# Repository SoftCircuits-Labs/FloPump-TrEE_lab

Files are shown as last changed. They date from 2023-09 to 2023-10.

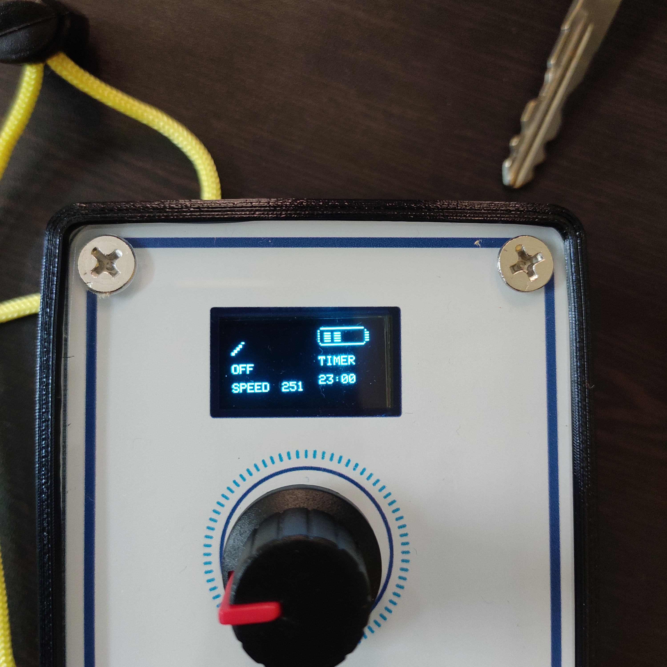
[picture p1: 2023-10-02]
AFC-DOCS/Images/Flopump_display.jpg

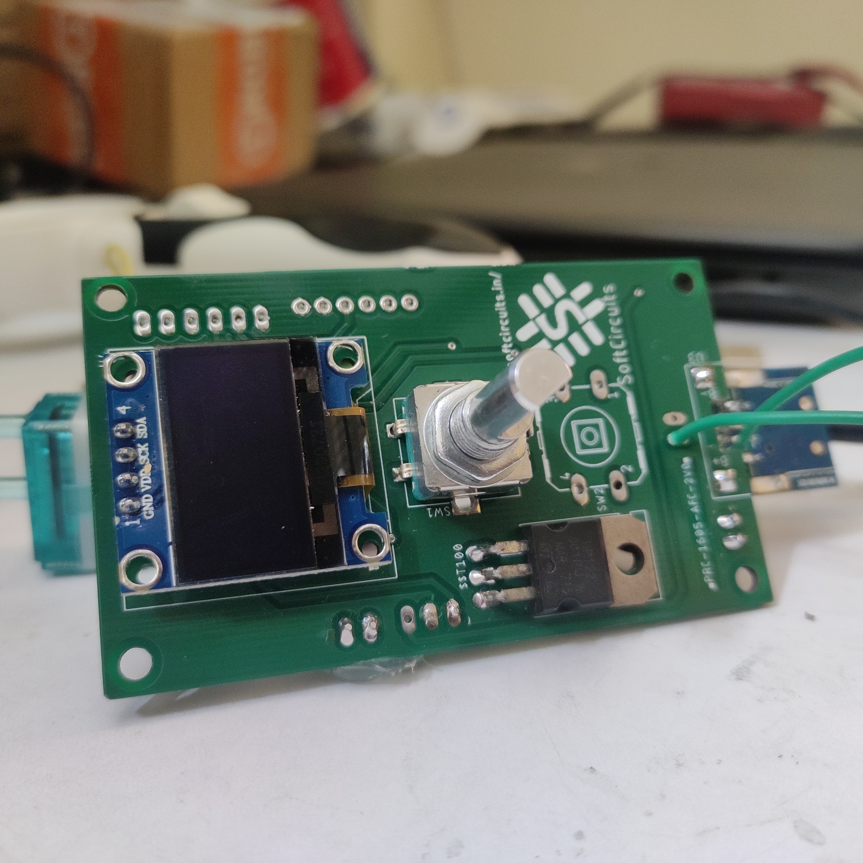
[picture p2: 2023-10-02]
AFC-DOCS/Images/Flopump_PCB.jpg

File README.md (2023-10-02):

<h1 align="center">AirFlo-pump</h1>

## About the  AirFlo-Pump Device
It is an air sampler device built for use in the applications that require a regulated air flow, for example sampling of VOCs from plants, room etc., or to generate a regulaed air flow in wind-tunnel experiments.

## Contents
<!---List file contents of the project, in table.--->

| File/folder | Description |
|---|---|
| `AFC-CODE` | Firmware for the device |
| `AFC-DOCS` | Device Images, User's Guide and other documents related to the device|
| `AFC-ENCLOSURE` | 3D Design files and DXF files for the enclosure |
| `AFC-PCB` | PCB Schematic files, board files and Gerber files |
| `LICENSE` | The license for the project. |
| `README.md` | This README file. |

## Built With
* [][Arduino-url]
* [][Eagle-url]
* [][Inventor-url]

## Usage

## Contact 

<!-- MARKDOWN LINKS & IMAGES -->
<!-- https://www.markdownguide.org/basic-syntax/#reference-style-links -->

[Arduino-l]: https://img.shields.io/badge/arduino-00878F?style=for-the-badge&logo=arduino&logoColor=white
[Arduino-url]: https://www.arduino.cc/
[Eagle-l]: https://img.shields.io/badge/Autodesk_Eagle-000000?style=for-the-badge&logo=autodesk&logoColor=white
[Eagle-url]: https://www.autodesk.in/products/eagle/overview
[Inventor-l]: https://img.shields.io/badge/Autodesk_Inventor-000000?style=for-the-badge&logo=autodesk&logoColor=white
[Inventor-url]: https://www.autodesk.in/products/inventor/overview

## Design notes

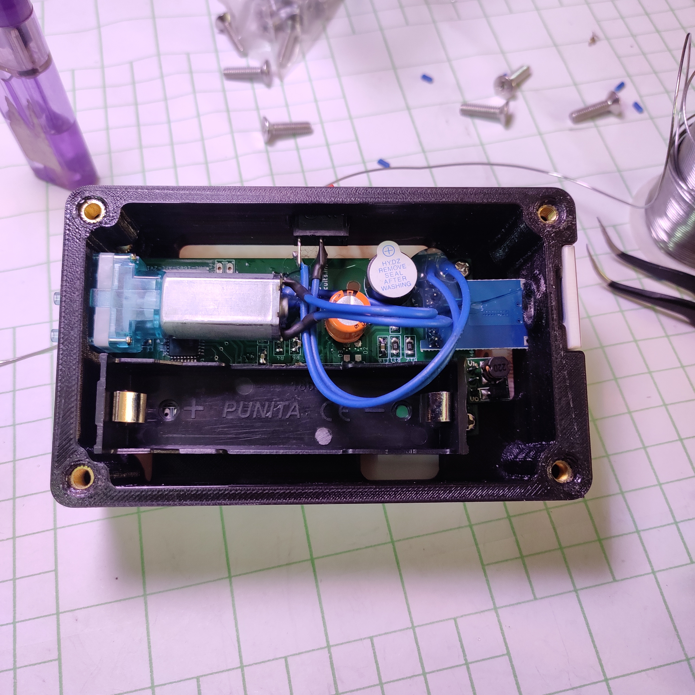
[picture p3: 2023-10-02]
AFC-DOCS/Images/Flopump_back-in.jpg

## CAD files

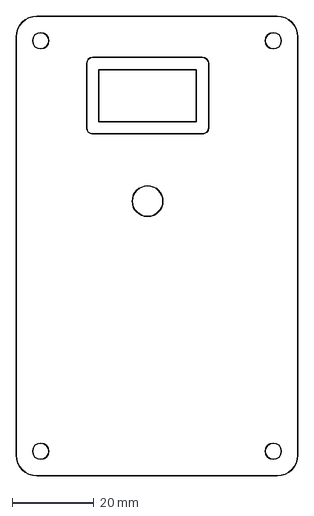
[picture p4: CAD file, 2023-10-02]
AFC-ENCLOSURE/dxf/front_acrylic.dxf
69.1 x 112.7 mm

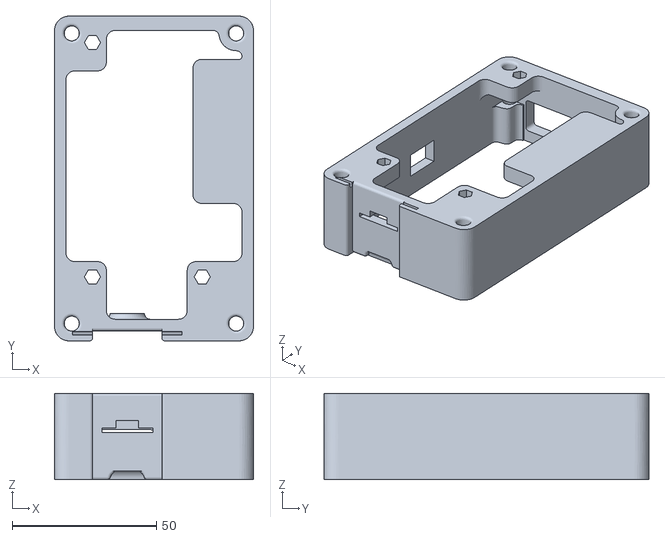
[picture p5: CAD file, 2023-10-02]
AFC-ENCLOSURE/STL/side_frame_v_2.stl
69.0 x 112.7 x 30.0

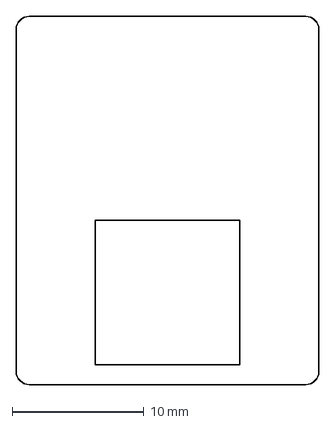
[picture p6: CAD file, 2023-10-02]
AFC-ENCLOSURE/dxf/usb_cap.dxf
23.0 x 28.0 mm

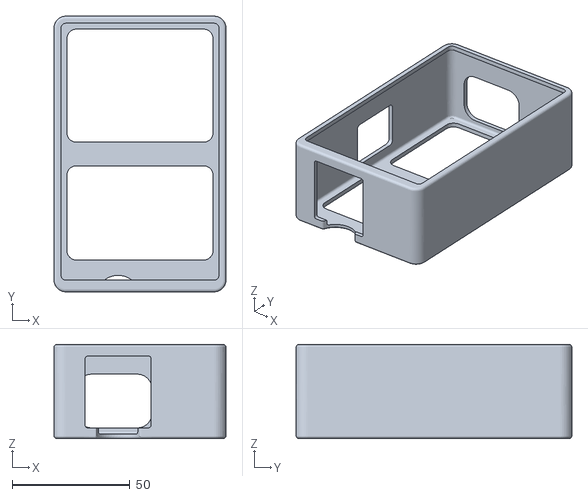
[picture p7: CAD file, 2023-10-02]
AFC-ENCLOSURE/STL/rubber_cover_v2.stl
73.0 x 117.0 x 40.0

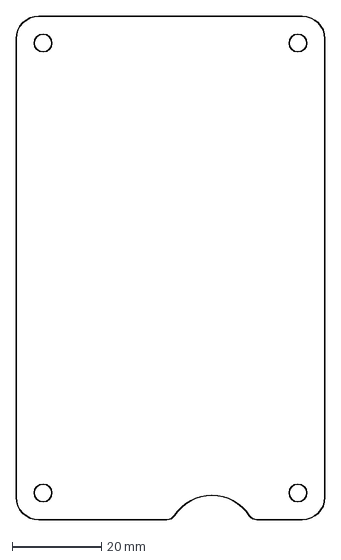
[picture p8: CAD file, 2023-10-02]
AFC-ENCLOSURE/dxf/back_acrylic.dxf
69.1 x 112.7 mm

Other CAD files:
AFC-ENCLOSURE/STL/side_frame.stl
AFC-ENCLOSURE/STL/rubber_cover.stl

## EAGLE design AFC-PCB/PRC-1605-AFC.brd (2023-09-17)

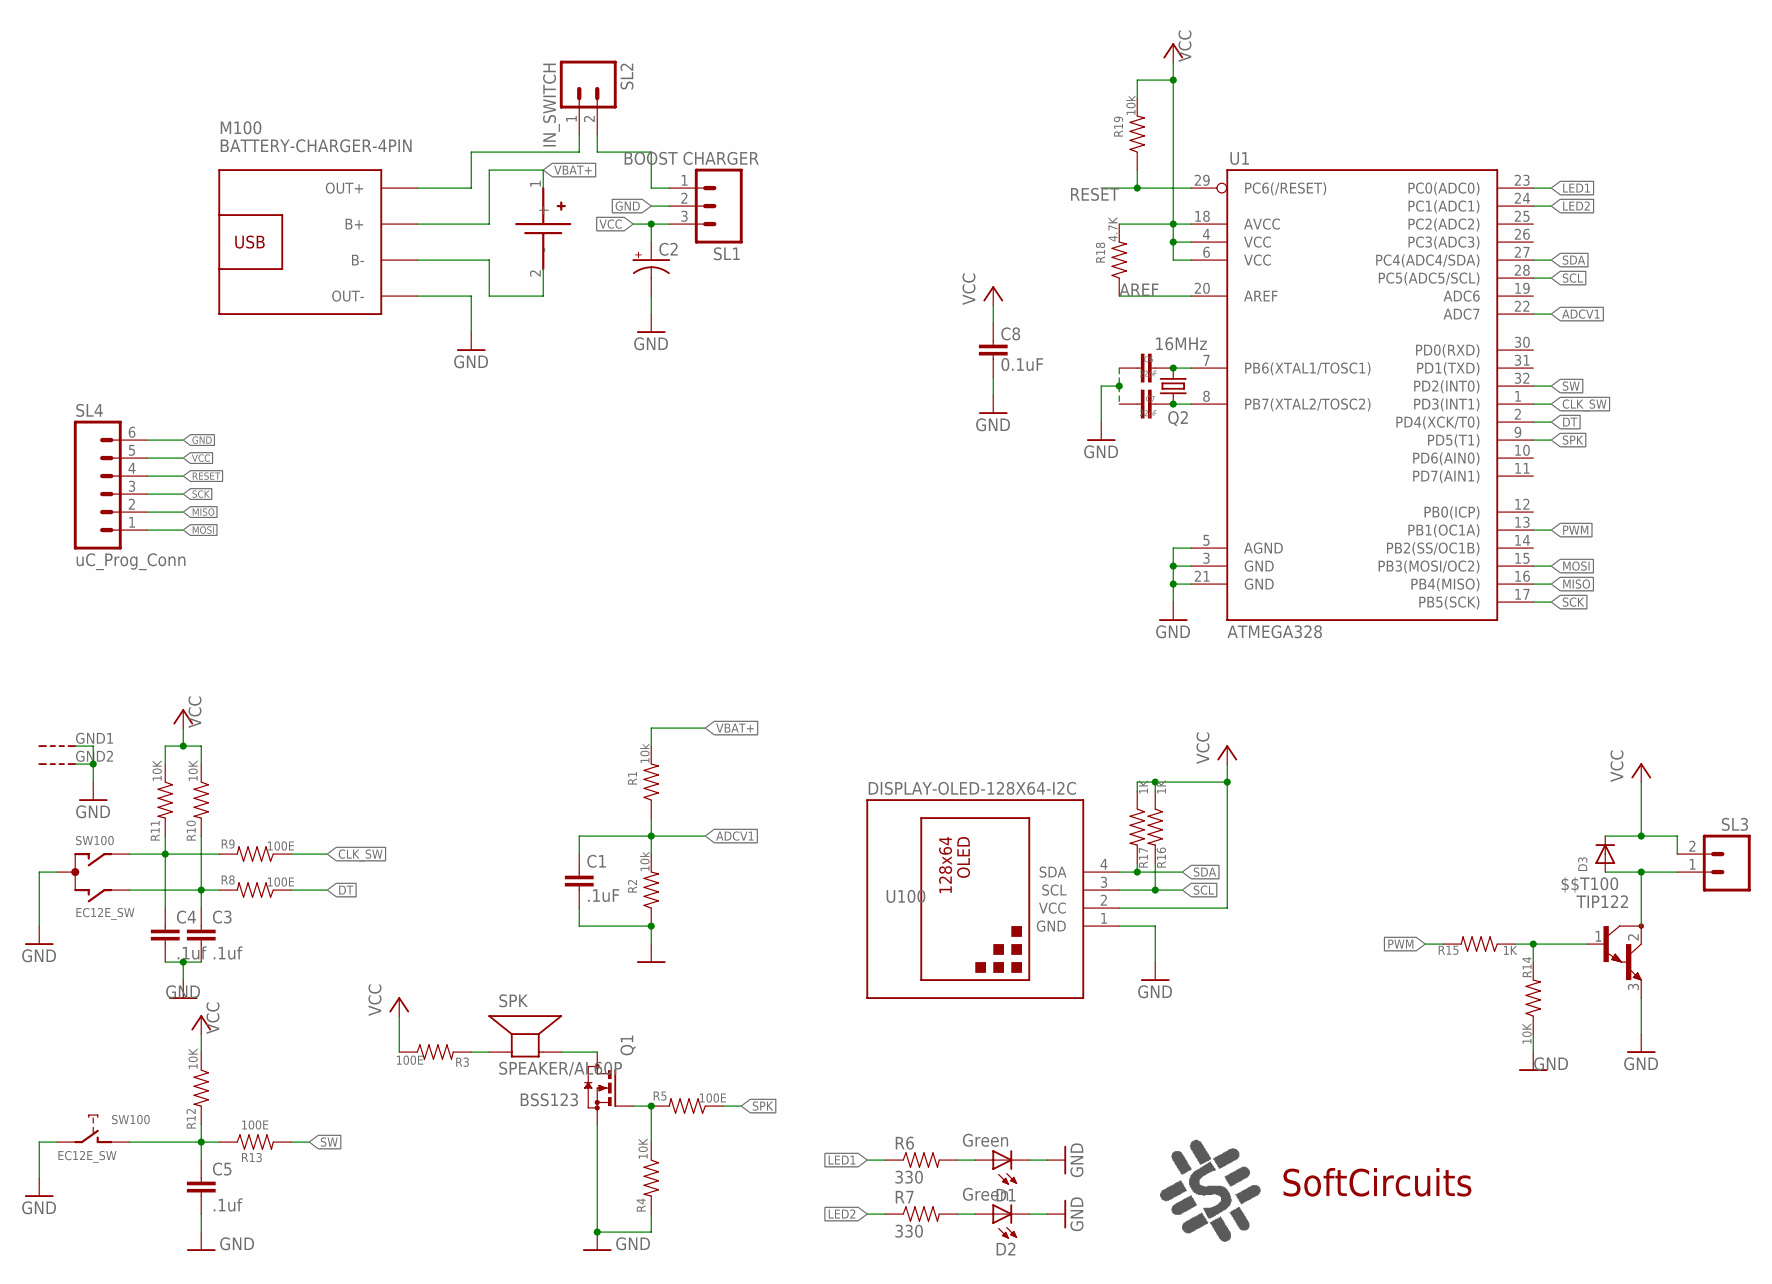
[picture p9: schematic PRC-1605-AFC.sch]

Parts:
$$T100: TIP122; TO220
C1: .1uF; C1206
C2: CPOL-USE2.5-7; E2,5-7
C3, C4, C5: .1uf; C1206
C6, C7: 22pF; C1206
C8: 0.1uF; C1206
D1, D2: Green; CHIPLED_1206
D3: DIODESMA; SMADIODE
LOGO100: SC_LOGO
M100: BATTERY-CHARGER-4PIN; BATTERY-CHARGER-LI-4PIN
Q1: BSS123; SOT23
Q2: 16MHz; HC49UP
R1, R2, R19: 10k; 1206
R3, R5, R8, R9, R13: 100E; 1206
R4, R10, R11, R12, R14: 10K; 1206
R6, R7: 330; 1206
R15, R16, R17: 1K; 1206
R18: 4.7K; 1206
SL1: BOOST CHARGER; 03P
SL2: IN_SWITCH; 02P
SL3: M02; 02P
SL4: uC_Prog_Conn; 06P
SPK: SPEAKER/AL60P; AL60P
SW100: EC12E_SW; ALPS_EC12E_SW
U1: ATMEGA328; TQFP32-08
U100: DISPLAY-OLED-128X64-I2C
U$2: BLOSSOM-BLM-18650-1PCS

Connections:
ADCV1: C1.1, R1.1, R2.2, U1.22 (ADC7)
AREF: R18.1, U1.20 (AREF)
CLK_SW: R9.1, U1.1 (PD3(INT1))
DT: R8.1, U1.2 (PD4(XCK/T0))
GND: $$T100.3 (E), C1.2, C2.-, C3.2, C4.2, C5.2, C6.2, C7.2, C8.1, D1.C, D2.C, M100.OUT-, Q1.2 (S), R2.1, R4.2, R14.1, SL1.2, SL4.6, SW100.C, SW100.E (2), SW100.GND1 (G), SW100.GND2 (G), U1.3 (GND), U1.5 (AGND), U1.21 (GND), U100.1 (GND)
LED1: R6.1, U1.23 (PC0(ADC0))
LED2: R7.1, U1.24 (PC1(ADC1))
MISO: SL4.2, U1.16 (PB4(MISO))
MOSI: SL4.1, U1.15 (PB3(MOSI/OC2))
unnamed: R3.2, SPK.1 (+)
unnamed: C5.1, R12.2, R13.1, SW100.D (1)
unnamed: Q1.3 (D), SPK.2 (-)
unnamed: SL1.1, SL2.2
unnamed: C4.1, R9.2, R11.2, SW100.A
unnamed: M100.B-, U$2.2 (-)
unnamed: Q1.1 (G), R4.1, R5.2
unnamed: D2.A, R7.2
unnamed: C3.1, R8.2, R10.2, SW100.B
unnamed: C7.1, Q2.1, U1.8 (PB7(XTAL2/TOSC2))
unnamed: C6.1, Q2.2, U1.7 (PB6(XTAL1/TOSC1))
unnamed: D1.A, R6.2
unnamed: $$T100.1 (B), R14.2, R15.1
unnamed: $$T100.2 (C), D3.A, SL3.1
PWM: R15.2, U1.13 (PB1(OC1A))
RESET: R19.1, SL4.4, U1.29 (PC6(/RESET))
SCK: SL4.3, U1.17 (PB5(SCK))
SCL: R16.2, U1.28 (PC5(ADC5/SCL)), U100.3 (SCL)
SDA: R17.2, U1.27 (PC4(ADC4/SDA)), U100.4 (SDA)
SPK: R5.1, U1.9 (PD5(T1))
SW: R13.2, U1.32 (PD2(INT0))
VBAT+: M100.B+, R1.2, U$2.1 (+)
VCC: C2.+, C8.2, D3.C, R3.1, R10.1, R11.1, R12.1, R16.1, R17.1, R18.2, R19.2, SL1.3, SL3.2, SL4.5, U1.4 (VCC), U1.6 (VCC), U1.18 (AVCC), U100.2 (VCC)
VOUT_CHG: M100.OUT+, SL2.1

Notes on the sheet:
SoftCircuits

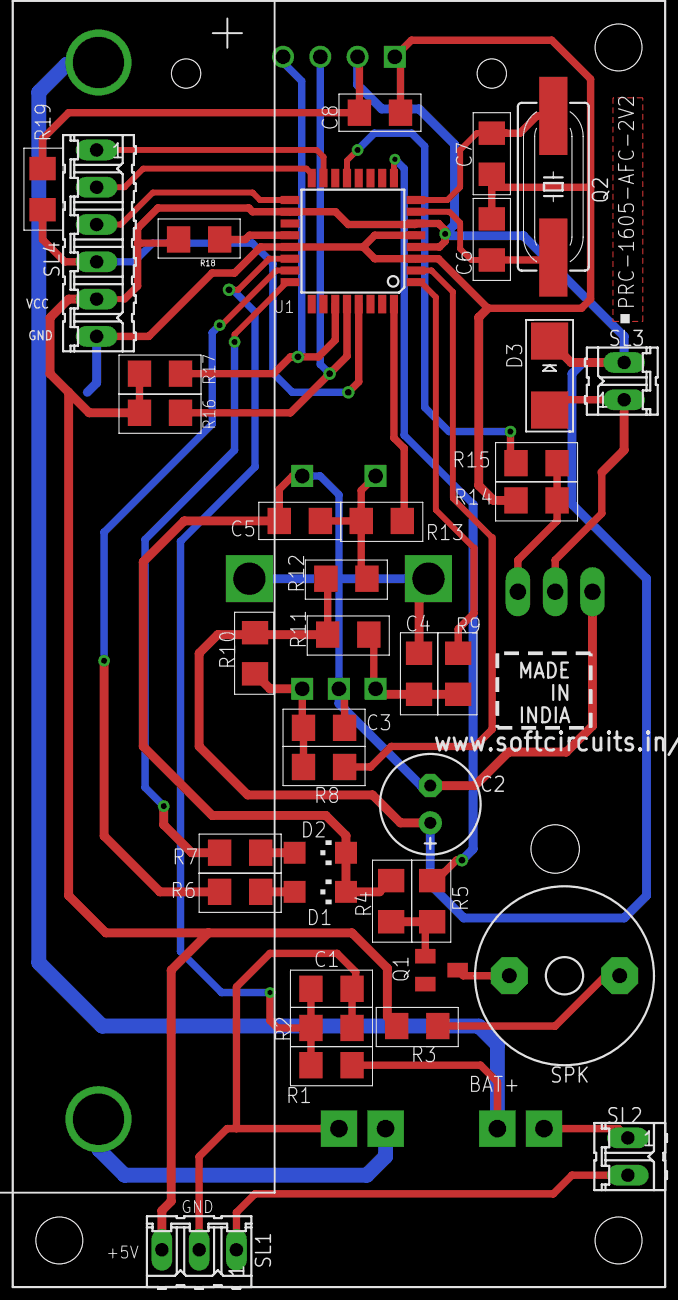
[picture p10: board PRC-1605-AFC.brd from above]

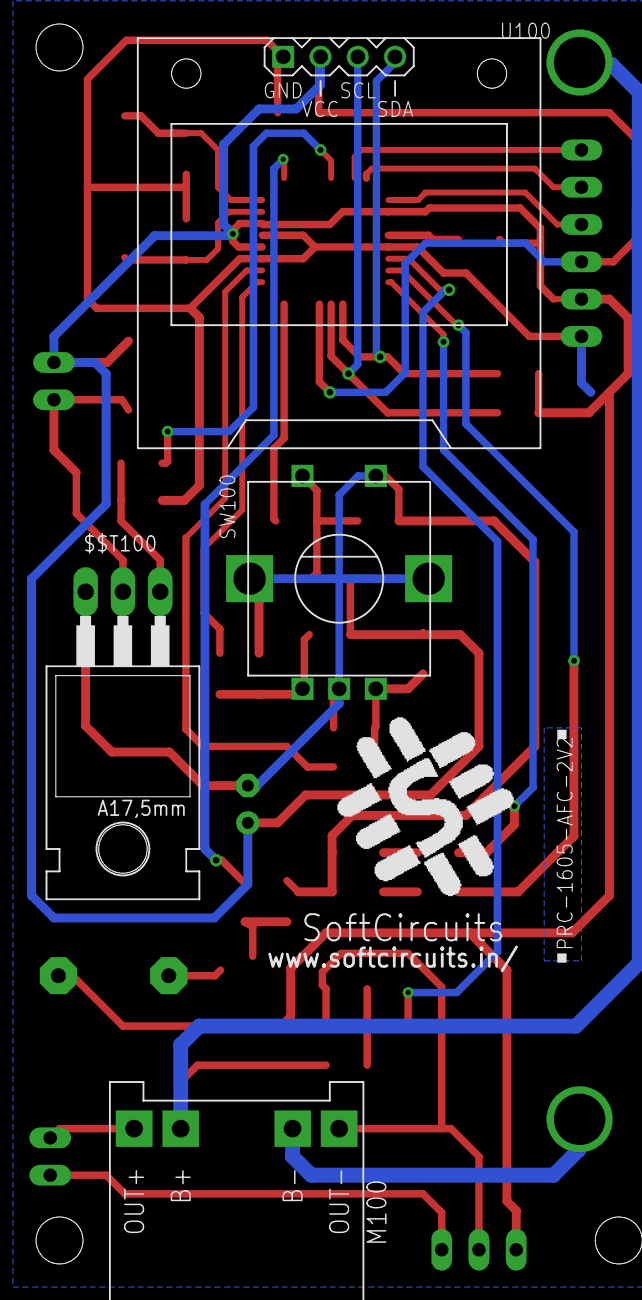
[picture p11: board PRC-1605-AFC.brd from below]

Board: 2 copper layers, 44 parts (5 on the bottom side), 33 nets.

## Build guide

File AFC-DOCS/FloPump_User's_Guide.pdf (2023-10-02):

# by SoftCircuits

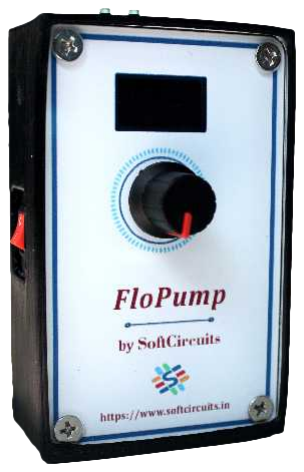
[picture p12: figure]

## https://www.softcircuits.in

# FloPump

# User Manual and Warranty informaon for

FloPump Devices.

# Please read this user manual carefully

before operang the device.

# User's Guide

Ver2.2 | Updated : June-2023 | 1

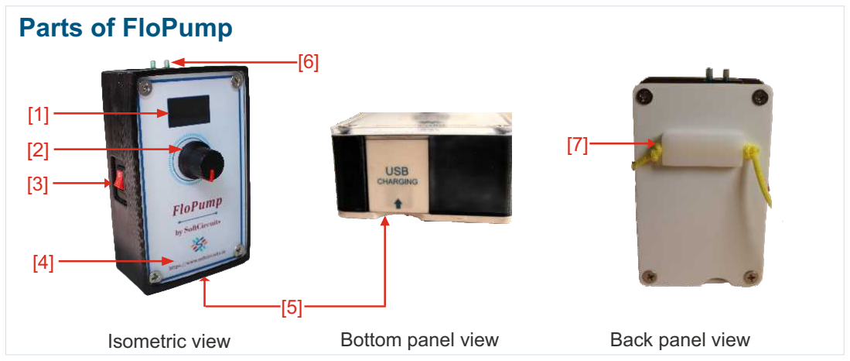
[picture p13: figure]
Isometric view; Bottom panel view; Back panel view; Parts of FloPump

### A. Device Operation

Battery Insertion
Ÿ | Remove the outer cover of the device to expose the back panel.
Ÿ | Remove the screws holding the back panel.
Ÿ | Place the battery inside the battery holder with correct polarity.
Ÿ | Fit the back panel again with the screws.
Charging the FloPump Device
Ÿ Whenever the battery is replaced, fully charge the device before switching it ON. On
| connecting the micro USB charger at Charging Port [5], Red light at the LED indicators [4]
| indicates device is charging and blue light indicates the battery is fully charged.
Ÿ | Before connecting the FloPump device to Air Flow Meter or any other device, check the
| device by flipping the ON switch [3]. If the display shows “Lo”/”Low” near the battery sign,
| charge the device before operation.
Setting the Parameters
Ÿ | Switch ON the device by flipping the ON Button [3]. The default settings of timer & flow-
| rate/pump-speed will be displayed.
Ÿ | Long press the knob button [2] for 5 seconds and the menu option “set timer” will be
| displayed. Now release the button and rotate the knob clockwise/anti-clockwise to
| increase/decrease the timer. Then press the button again at the timer value you want to set.
| Now the display will revert to main screen showing set values of the timer.
Ÿ | Similarly, long-press the knob button for 10 seconds to disable/enable the timer.
Ÿ | The flow rate/ Pump speed can be changed by rotating the knob when main screen is
| displayed.
[5] USB Charging port
[6] Pump Inlet & Outlet
[7] Drawstring for device attachment
[1] OLED display
[2] Rotary Knob
[3] Main ON-OFF switch
[4] Battery Charging LED Indicators
Ver2.2 | Updated : June-2023 | 2

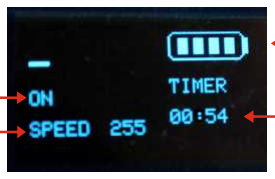
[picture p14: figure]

### D. Purpose of the User Manual

The User Manual provides you with instructions and information to use the FloPump device. It also includes relevant guidance for practical handling and maintenance of the device. However, the flow-rate calibration should be done by the user using a flow-meter as per the guidelines of flow-meter.

### E. Device Applications

SoftCircuits FloPump device is intended for use in the applications that require a regulated air flow, for example sampling of VOCs from plants, room etc., or generate a regulaed air flow in wind-tunnel experiments..

### F. Cautions and Warnings

Ÿ | When working with the FloPump device, air flow meters and accompanying electronics,
| follow the standard procedures to protect the devices from damage or any other
| malfunctioning.
Ÿ | All users must read and understand all documentation for the FloPump devices and
| components before operating or maintaining the device.
Ÿ | Do not operate the device in any other way than described in the user documentation. If you
| do, you may be exposed to hazards that can lead to personal injury and you may cause
| damage to the equipment.
Ÿ | Extra care must be taken when using the electronic components with fluids.
Ÿ | Take special care while charging the device. Do not charge the device at currents higher than
| the maximum allowed rating (1A).
Ÿ | Do not operate the device while charging. It may lead to device malfunction or personal
| injuries.

### C. Product Specifications :

Device Version : VSU-2V0, VSU-2V1, VSU-2V2 Battery Details :
Ÿ | Capacity- 2500mAh, 9.25WH
Ÿ | Type – Li-ion rechargeable 18650 battery, 3.7V, removable
Ÿ | Charging input current- 1A
Maximum flow rate : 800mL/min
Device Weight : 200g

### B. Display Indicators

[Battery Level Indicator]

[Time Remaining : mm:ss]

[Running Status : ON/OFF]
[Air Pump Speed : 0 to 255]

Operating the Device
Ÿ | Once parameters are set, pressing the knob button will start the FloPump with the selected
| flow-rate and the pump will stop automatically once the timer is over.
Ÿ | Alternatively, pressing the button again will stop the device.
Ver2.2 | Updated : June-2023 | 3

Ver2.2 | Updated : June-2023 | 4

SoftCircuits Cloud Innovation Pvt. Ltd. Sultanpur Colony, New Delhi-110030, India

connect@softcircuits.in

https://www.softcircuits.in

Please reach out to us for any queries or complains at : +91-8376945916

### Warranty Information

Ÿ | SoftCircuits provides a warranty on all parts and factory workmanship. The warranty
| includes areas of defective material and workmanship, provided such defect results from
| normal and proper use of the equipment.
Ÿ | The warranty for all products will expire one year from date of shipment from SoftCircuits
| warehouse.
Ÿ | This warranty covers replacement of the defected device, but not transportation and
| insurance charges.
Ÿ | In the event of a warranty claim, contact SoftCircuits as soon as possible. If the cause is
| determined to be a manufacturing fault, SoftCircuits will repair or replace defective device.
| Under no circumstances shall SoftCircuits be held liable for indirect, consequential or special
| damages of any kind while the device is with the client.
- No individual has authorization to alter the provisions of this warranty policy or its
| amendments.
- The liability of SoftCircuits lies only up to the FloPump device and any damage to the
| devices connected to FloPump device shall be user's responsibility.
- Damage due to corrosion or accidental breakage is not covered.

### Returned or Damaged Goods

Ÿ Do not return goods without the prior authorization from SoftCircuits. Unauthorized returns
| will not be accepted. If your shipment was damaged in transit, you must file a claim directly
| with the freight carrier. SoftCircuits is not responsible for shipping damages.
Ÿ | All users of this equipment are required to become familiar with any regulations that apply in
| the user's area concerning the dumping of waste materials in or upon water, land or air and to
| comply with such regulations. SoftCircuits is held harmless with respect to user's compliance
| with such regulations

The information contained in this manual and the accompanying products are all rights reserved by SoftCircuits, provided exclusively to the party buying the devices from SoftCircuits. SoftCircuits can make periodic design changes in order to meet industry standards or enhance device features.

Designed & Manufactured by

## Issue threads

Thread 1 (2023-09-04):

Update to the latest version (Arduino Based)

SoftCircuits-Innovation, 2023-09-04:
Current version is based on Atmega customized hardware & firmware. The latest version is Arduino based ( Hardware & Firmware) and the code & PCB files need to be updated accordingly.

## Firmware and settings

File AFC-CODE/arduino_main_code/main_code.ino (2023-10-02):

#include <EEPROM.h>
#include <Wire.h>
#include <Adafruit_GFX.h>
#include <Adafruit_SSD1306.h>

#define SCREEN_WIDTH 128 // OLED display width, in pixels
#define SCREEN_HEIGHT 64 // OLED display height, in pixels

// Declaration for an SSD1306 display connected to I2C (SDA, SCL pins)
#define OLED_RESET     -1 // Reset pin # (or -1 if sharing Arduino reset pin)
Adafruit_SSD1306 display(SCREEN_WIDTH, SCREEN_HEIGHT, &Wire, OLED_RESET);

#define BUZZER_PIN 5
#define ENC_BUTTON_PIN 2
#define ENC_DATA_PIN 4
#define ENC_CLK_PIN 3
#define MOT_PWM_PIN 9
#define LED_1_PIN 14
#define LED_2_PIN 15
#define BAT_ADC_PIN A7

#define BAT_MIN 320
#define BAT_MAX 420 

//---------------EEPROM ADDRESS---------------
#define EP_ADD_PWM 10
#define EP_ADD_TIME 20
#define EP_ADD_ENABLE 30
//-------------STATE VARIABLES-----------------
#define BOOTING_STATE 0
#define PUMP_ON_OFF_STATE 1
#define SET_TIME_STATE 2
#define ENABLE_TIMER_STATE 3
#define TIMER_EXPIRE_STATE 4
#define EXIT_STATE 5

unsigned char state = BOOTING_STATE;
//---------------------------------------------
#define PWM_MAX 255
#define PWM_MIN 100

#define TIMER_MAX 999
#define TIMER_MIN 1

//---------------------------------------------
#define TIMER_EXPIRE_BUZZER 10000
//---------------------------------------------

unsigned char motor_on_off_state=0;

unsigned char animate_pump_var=0;

volatile unsigned char pwm = PWM_MIN;
volatile unsigned int timer_time = TIMER_MIN;
volatile unsigned char timer_enable = 1;
unsigned char last_pwm=0;

unsigned char enc_button_val = 0; 
unsigned int button_time=0;
unsigned long start_time=0;
unsigned long passed_seconds=0;
unsigned long display_minutes = 0;
unsigned long display_seconds = 0;

unsigned int battery_display_time = 0;
unsigned int battery_voltage_last = 0,battery_voltage_current=0,battery_voltage_difference=0;
unsigned int timer_expire_buzzer = 0;


void setup() {
  // put your setup code here, to run once:
//Serial.begin(9600);
init_motor();
init_buzzer();
init_batter_ADC();
init_encoder_sw();
oled_init();
fetch_eeprom();
delay(10);
buzzer(400);
delay(400);
buzzer(400);
}

void loop() {   
  /*
  while(1){
      display.clearDisplay();
    display.setCursor(15,10);   
    display.setTextSize(2);                
    battery_voltage_current = read_battery_voltage();      
    display.print(battery_voltage_current);
    display.display();
    delay(400);
    
    }
  */
  // put your main code here, to run repeatedly:  
 switch(state){    
    case BOOTING_STATE :
    display.clearDisplay();
    display.setCursor(15,10);   
    display.setTextSize(2);                
    display.print(F("Flo-Pump"));
    display.setCursor(58,32);   
    display.setTextSize(1);                
    display.print(F("by"));
    display.setCursor(5,50);   
    display.print(F("www.softcircuits.in"));
    display.display();
    delay(2000);
    state = PUMP_ON_OFF_STATE;
    display_pump_on_off_page();
    break;
    
    case PUMP_ON_OFF_STATE : 
    buzzer_off();                  
    if(last_pwm != pwm){
        last_pwm = pwm;
          if(motor_on_off_state == 1){
            start_motor(last_pwm);    
          }        
        display.fillRect(50, 45, 21, 7,SSD1306_BLACK);
        display.setTextSize(1);
        display.setCursor(50,45);          
        display.print(pwm);    
        display.display();
      }

      button_time=0;
    while(digitalRead(ENC_BUTTON_PIN) == LOW){        
        delay(1);
        button_time++;             
        if(button_time==3000){
            display.clearDisplay();
            display.setTextSize(1);
            display.setCursor(40,25);
            display.print(F("SET TIMER"));     
            display.display();  
        }else if(button_time==7000){
            display.clearDisplay();
            display.setTextSize(1);
            display.setCursor(30,25);
            display.print(F("ENABLE TIMER"));     
            display.display();  
        }else if(button_time==11000){
            display.clearDisplay();
            display.setTextSize(1);
            display.setCursor(48,25);
            display.print(F("EXIT"));     
            display.display();  
            delay(1000);
            break;
          }
        
      }  
    if(button_time>=100 && button_time<1000){
      if(motor_on_off_state == 0 ){
          motor_on_off_state=1;
          start_motor(pwm);
          EEPROM.update(EP_ADD_PWM, pwm);
          display.fillRect(10, 30, 21, 7,SSD1306_BLACK);          
          display.setTextSize(1);      
          display.setCursor(10,30);
          display.print("ON");
          display.display(); 
          start_time = millis();
        }else{          
          motor_on_off_state=0;  
          stop_motor();
          EEPROM.update(EP_ADD_PWM, pwm);
          display.fillRect(10, 30, 21, 7,SSD1306_BLACK);          
          display.setTextSize(1);      
          display.setCursor(10,30);
          display.print("OFF");
          display.display(); 
        }
      
      }else if(button_time>=3000 && button_time<7000){
        state = SET_TIME_STATE;
        break;
      
      }else if(button_time>=7000 && button_time<11000){
        state = ENABLE_TIMER_STATE;
        break;
        
      }else if(button_time>=11000){
        
        display_pump_on_off_page();
        break;
      }  

    if(motor_on_off_state){
        animate_running_pump();
        if(timer_enable){
            remaining_timer_routine();   
          }else{
            display.fillRect(80, 40, 40, 7,SSD1306_BLACK);          
            display.setTextSize(1);      
            display.setCursor(80,40);
            display.print("DISABLED");
            display.display(); 
            }
        
      }
     if((millis()-battery_display_time) > 10000){
        battery_voltage_current = 0;
        
        battery_voltage_current += read_battery_voltage();
        battery_voltage_current += read_battery_voltage();
        battery_voltage_current += read_battery_voltage();
        battery_voltage_current += read_battery_voltage();

        battery_voltage_current/=4;
        if(battery_voltage_current>battery_voltage_last){
          battery_voltage_difference = battery_voltage_current - battery_voltage_last;
        }else{
          battery_voltage_difference = battery_voltage_last - battery_voltage_current;  
        }        

        if(battery_voltage_difference > 5){
            if(battery_voltage_current > BAT_MIN){
                display_battery_charge(((battery_voltage_current - BAT_MIN)*100)/(BAT_MAX-BAT_MIN)); 
              }else{
                display_battery_charge(10);// this will show low battery 
                }
                
            battery_voltage_last = battery_voltage_current;  
          }
        
        battery_display_time = millis();
      }      
    delay(10);
    //state = SET_TIME_STATE;
    break;
    
    case SET_TIME_STATE :
        display.clearDisplay();
        display.setCursor(20,20);   
        display.print(F("SET TIME "));
        display.print(timer_time);
        display.print(F(" min"));
        display.display();
        delay(10);
        if(digitalRead(ENC_BUTTON_PIN) == LOW){
          state = PUMP_ON_OFF_STATE;   
          //EEPROM.update(EP_ADD_TIME, timer_time);       
          EEPROM.put(EP_ADD_TIME, timer_time);       
          delay(200);
          start_time = millis();
          display_pump_on_off_page();
          }    
    break;
    
    case ENABLE_TIMER_STATE :
        display.clearDisplay();
        display.setCursor(20,20);   
          if(timer_enable){
            display.print(F("ENABLE TIMER "));  
          }else{
            display.print(F("DISABLE TIMER "));
          }
        
        //display.print(timer_enable);
        display.display();
        delay(10);
        if(digitalRead(ENC_BUTTON_PIN) == LOW){
          state = PUMP_ON_OFF_STATE;
          EEPROM.update(EP_ADD_ENABLE, timer_enable);
          delay(200);
          display_pump_on_off_page();
          }    
    break;

    case TIMER_EXPIRE_STATE :
        
        if(timer_expire_buzzer%50 == 0){
            display.clearDisplay();
            display.setCursor(40,10);   
            display.print(F("TIMER END"));            
            display.display();  
            if(timer_expire_buzzer < (TIMER_EXPIRE_BUZZER/10)) buzzer_on();
          }else if(timer_expire_buzzer%50 == 25){
            display.clearDisplay();
            display.setCursor(40,10);   
            display.print(F("TIMER-END"));            
            display.display();
            buzzer_off();
          }
        timer_expire_buzzer++;    
        delay(10);        
        
            
           

         if(digitalRead(ENC_BUTTON_PIN) == LOW){
          buzzer_off();
          state = PUMP_ON_OFF_STATE;             
          delay(200);          
          display_pump_on_off_page();
          } 
        
    break;
    
    case EXIT_STATE :
    display.clearDisplay();
    display.setCursor(40,10);   
    display.println(F("EXIT_STATE"));
    display.display();
    delay(1000);
    state = BOOTING_STATE;
    break;
    
  }

}

void oled_init(){
     if(!display.begin(SSD1306_SWITCHCAPVCC, 0x3C)) { // Address 0x3D for 128x64
    //Serial.println(F("SSD1306 allocation failed"));
    for(;;); // Don't proceed, loop forever
  }

  // Show initial display buffer contents on the screen --
  // the library initializes this with an Adafruit splash screen.
  //display.display();
  //delay(2000); // Pause for 2 seconds

  display.setTextSize(1);
  display.setTextColor(WHITE);
  // Clear the buffer
  display.clearDisplay();  
  }
//-------------------------motor--------------
void init_motor(){
  pinMode(MOT_PWM_PIN, OUTPUT);
  digitalWrite(MOT_PWM_PIN, LOW);  
  }  
void start_motor(unsigned char mot_speed){
  analogWrite(MOT_PWM_PIN, mot_speed);
  }
void stop_motor(){
  analogWrite(MOT_PWM_PIN,0);
  }  
 
//------------------------encoder switch---------
void init_encoder_sw(){
  pinMode(ENC_BUTTON_PIN, INPUT);
  pinMode(ENC_DATA_PIN, INPUT);
  pinMode(ENC_CLK_PIN, INPUT);

  digitalWrite(ENC_BUTTON_PIN, HIGH);  
  digitalWrite(ENC_DATA_PIN, HIGH);
  digitalWrite(ENC_CLK_PIN, HIGH);  

  attachInterrupt(digitalPinToInterrupt(ENC_CLK_PIN), encoder_ISR, FALLING);
  
  }

void encoder_ISR(){
  noInterrupts ();  
  switch(state){
    case PUMP_ON_OFF_STATE :
    if(digitalRead(ENC_CLK_PIN)==LOW){    
      if(digitalRead(ENC_DATA_PIN)==HIGH){
        if(pwm>PWM_MIN)pwm--;    
      }else{
        if(pwm<PWM_MAX)pwm++;        
      }
    }
    break;

    case SET_TIME_STATE :
    if(digitalRead(ENC_CLK_PIN)==LOW){    
      if(digitalRead(ENC_DATA_PIN)==HIGH){
        if(timer_time>TIMER_MIN){
          if(timer_time<=60){
            timer_time--;        
          }else{
            timer_time-=5;            
          }
        }
      }else{
        if(timer_time<TIMER_MAX){
          if(timer_time>=60){
            timer_time+=5;        
          }else{
            timer_time++;            
          }
          
        }
      }
    }
    break;

    case ENABLE_TIMER_STATE :
    if(digitalRead(ENC_CLK_PIN)==LOW){    
      if(digitalRead(ENC_DATA_PIN)==HIGH){
        timer_enable=0;    
      }else{
        timer_enable=1;        
      }
    }
    break;
    }
    delayMicroseconds(50000);
    interrupts ();    
  }  



unsigned char read_sw(){
  unsigned int x=0;
  if(digitalRead(ENC_BUTTON_PIN) == LOW){
    for(x=0;x<10000;x++){
      delay(1);
      if(digitalRead(ENC_BUTTON_PIN) == HIGH) break;
      }
    if(x>200 && x<3000) return 1;
    if(x>=3000 && x<6000) return 2;  
    if(x>=6000 && x<9000) return 3;
    if(x>=9000) return 4;
  }else{
    return 0;
    }
  }  

void display_pump_on_off_page(){
      display.clearDisplay();
      display.setTextSize(2);      
      display.setCursor(10,10);   
      display.print(F("/"));    
      display.setTextSize(1);      
      display.setCursor(10,30);   
      display.print(F("OFF"));  
      //display.setTextSize(2);      
      display.setCursor(10,45);   
      display.print(F("SPEED")); 
      display.setCursor(50,45);   
      display.print(pwm); 
      display.setCursor(80,25);   
      display.print(F("TIMER")); 
      display.setCursor(80,40);   
      if(timer_time<10)display.print("0");
      display.print(timer_time);
      display.print(F(":00")); 
      display.display();    

      display_battery_charge(100);
  }
void display_timer_set_page(){
      display.clearDisplay();
      display.setTextSize(2);      
      display.setCursor(10,10);   
      display.print(F("SET TIMER"));    
      display.setTextSize(1);      
      display.setCursor(80,40);   
      display.print(F("Minutes"));  
      display.setTextSize(2);      
      display.setCursor(20,36);   
      display.print(F("1000")); 
      display.display();      
  }  
void display_timer_enable_page(){
      display.clearDisplay();
      display.setTextSize(2);      
      display.setCursor(40,10);   
      display.print(F("TIMER"));    
      display.setTextSize(2);      
      display.setCursor(32,36);   
      display.print(F("Enable"));        
      display.display();      
  }

void animate_running_pump(){
    display.fillRect(10, 10, 14, 14,SSD1306_BLACK);  
    display.setTextSize(2);       
    display.setCursor(10,10);
    switch(animate_pump_var){
      case 0:
        display.print(F("\\"));            
      break;
      case 1:
        display.print(F("|"));            
      break;
      case 2:
        display.print(F("/"));            
      break;
      case 3:
        display.print(F("-"));            
      break;
      }
    display.display();  
    animate_pump_var++;
    if(animate_pump_var>3)animate_pump_var=0;
    
  } 

 void remaining_timer_routine(){
      passed_seconds = (millis() - start_time)/1000;
      if(passed_seconds<timer_time*60){
          display.fillRect(80, 40, 40, 7,SSD1306_BLACK);          
          display.setTextSize(1);      
          display.setCursor(80,40);
          display_seconds = (timer_time*60 - passed_seconds)%60;
          display_minutes = (timer_time*60 - passed_seconds)/60;
          if(display_minutes<10)display.print("0");
          display.print(display_minutes);
            if(millis()%1000 > 500){
              display.print(":");  
            }else{
              display.print(" ");
            }
          if(display_seconds<10)display.print("0");
          display.print(display_seconds);
          display.display(); 
        }else{
          motor_on_off_state=0;  
          stop_motor();
          timer_expire_buzzer=0;
          state = TIMER_EXPIRE_STATE;
          EEPROM.update(EP_ADD_PWM, pwm);
          display.fillRect(10, 30, 21, 7,SSD1306_BLACK);          
          display.setTextSize(1);      
          display.setCursor(10,30);
          display.print("OFF");
          display.fillRect(80, 40, 40, 7,SSD1306_BLACK);          
          display.setCursor(80,40);
          display.print("00:00");
          display.display(); 
          } 
  }

     

void fetch_eeprom(){
    pwm = EEPROM.read(EP_ADD_PWM);
    //timer_time = EEPROM.read(EP_ADD_TIME);
    EEPROM.get(EP_ADD_TIME,timer_time);
    timer_enable = EEPROM.read(EP_ADD_ENABLE);

    if(pwm>PWM_MAX || pwm<PWM_MIN){
      pwm = PWM_MIN;
      EEPROM.update(EP_ADD_PWM, pwm);
      }
     if(timer_time>TIMER_MAX || timer_time<TIMER_MIN){
      timer_time = TIMER_MIN;
      EEPROM.update(EP_ADD_TIME, timer_time);
      } 
      if(timer_enable!=0 && timer_enable!=1){
      timer_enable = 1;
      EEPROM.update(EP_ADD_ENABLE, 1);
      }   
  }



void display_battery_charge(unsigned int charge){  
      display.fillRect(52, 0, 80, 18,SSD1306_BLACK);
      display.setTextSize(1);      
      display.setCursor(52,6);
      if(charge<=30){
        display.print(F("LOW"));
        }
      //display.print(charge);
      //display.print(F("%"));       
      display.drawRoundRect(80, 2, 39, 14,3, SSD1306_WHITE);
      display.fillRect(119, 5, 2, 8,SSD1306_WHITE); 


      if(charge>20)display.fillRect(85, 5, 5, 8,SSD1306_WHITE); 
      if(charge>40)display.fillRect(93, 5, 5, 8,SSD1306_WHITE); 
      if(charge>60)display.fillRect(101, 5, 5, 8,SSD1306_WHITE);
      if(charge>80)display.fillRect(109, 5, 5, 8,SSD1306_WHITE);
      display.display();     
  }  

void init_buzzer(){
  pinMode(BUZZER_PIN, OUTPUT);
  digitalWrite(BUZZER_PIN, LOW);  
  } 

void buzzer(unsigned long beep_time){
    digitalWrite(BUZZER_PIN, HIGH);
    delay(beep_time);
    digitalWrite(BUZZER_PIN, LOW);    
  } 

void buzzer_on(){
    digitalWrite(BUZZER_PIN, HIGH);    
  }   

void buzzer_off(){
    digitalWrite(BUZZER_PIN, LOW);    
  }

void init_batter_ADC(){
  pinMode(BAT_ADC_PIN, INPUT);
  }
 unsigned int read_battery_voltage(){
  return analogRead(BAT_ADC_PIN);    
  }          

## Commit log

2023-09-17 Folder Names Changed for Clarity
    [PRC-16105-AFC-1V1.brd, PRC-16105-AFC-1V1.sch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]
2023-09-17 Updated the hardware design
    Updated the hardware to the latest version.
    [PRC-1605-AFC.brd, PRC-1605-AFC.sch, PRC-16105-AFC-1V1.brd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]
2023-10-02 Updated 3D Files and Arduino code for latest version
    [back_acrylic.dxf, front_acrylic.dxf, rubber_cover.stl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]

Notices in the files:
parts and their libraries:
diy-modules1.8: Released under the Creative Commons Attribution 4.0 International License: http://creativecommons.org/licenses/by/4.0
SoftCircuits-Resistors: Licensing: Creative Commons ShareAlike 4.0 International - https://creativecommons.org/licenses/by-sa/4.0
